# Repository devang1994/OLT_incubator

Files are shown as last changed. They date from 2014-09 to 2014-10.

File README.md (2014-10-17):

# OpenLabTools Incubator

## Introduction
The incubator project aims to make a cost-effective open-source customizable incubator from of the shelf components for use primarily in biology research

The project has been designed to be fully compatible with OpenLabTools Web interface to provide ease of control and access. Because of the web based interface the incubator can also be controlled and monitored remotely.

## Temperature Control

Peltier modules have been used as the basic heat transfer component for the incubator.
Peltier modules act as solid state heat pumps allowing us to either cool or heat the module by simply switching the current going into the module.

An off the shelf CPU heatsink with fan has been attached to both the sides of the peltier modules to effectively dissipate heat to either the surroundings or the incubation chamber.

## Electronics

A simple [H-Bridge](http://en.wikipedia.org/wiki/H_bridge) circuit was designed and made using off the shelf relays and darlington transistors. The H-Bridge is controlled by the micro-controller which allows current to pass in either direction across the peltier module allowing us to either heat or cool the system.

A DHT 22 sensor is used to detect the temperature in the box to do appropriate control.

## Microprocessor

Arduino UNO has been used as the micro-controller for this application, it can be controlled by sending the required temperature to it via the serial protocol, it also reads the temperature in the incubator and returns it via the serial protocol.

The code has been written using the Arduino IDE.

## Incubator chamber

The current  incubator chamber has been made using a 2mm acrylic sheet, this can be changed to suit particular needs of the application.

The acrylic sheet sheet has been milled using the [Shapeoko 2](http://docs.shapeoko.com/) Desktop CNC milling machine to make the required holes for fitting in the peltier modules and associated heatsinks as shown in the image below.

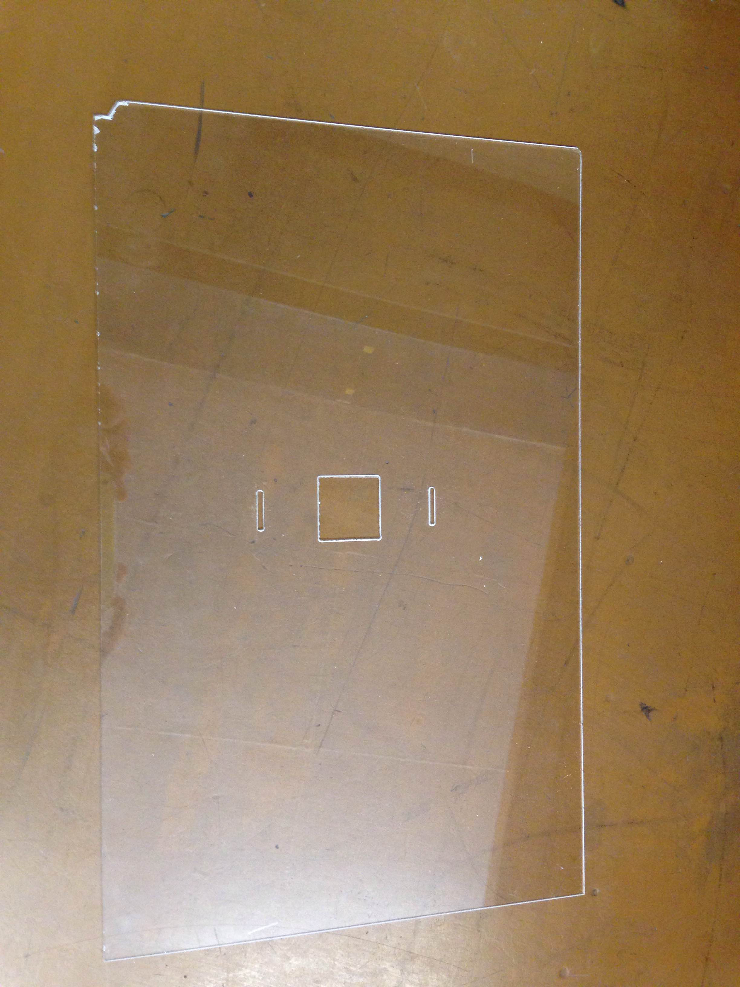
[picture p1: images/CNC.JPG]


The individual acrylic sheets are held together using angled holding brackets which were 3d printed using the MakerBot Replicator 3d printer

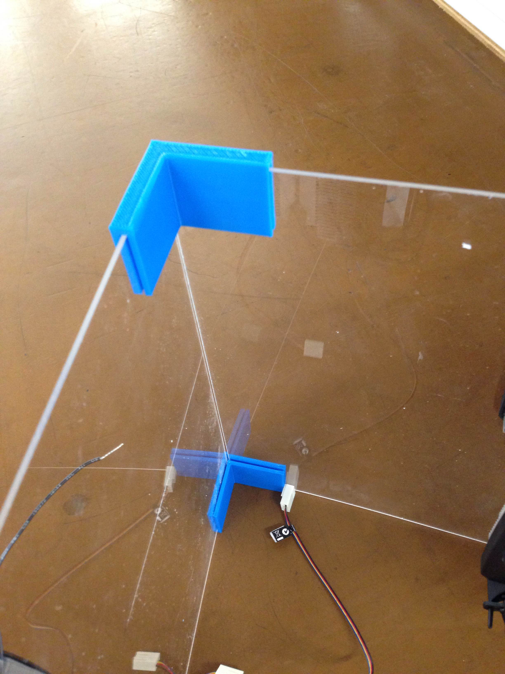
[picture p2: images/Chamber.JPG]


## Development Notes

To do:

1. Replace relays with power MOSFETs
2. Use PWM to do PID control of the temperature
3. Redesign Holding Brackets to have even smaller air gaps at joints or explore possibility of using acrylic cement or another similar product

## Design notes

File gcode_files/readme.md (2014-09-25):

Gcode instructions

The code was written using easel an online CAM package

The gcode was then sent to the shapeoko2 desktop cnc machine using universal gcode sender details about which can be found in docs.shapeoko.com

The file sideplate was used to cut the acryclic sheet to fit in the pelier modules and heatsinks into it

holding bracket was used to make a part for holding the 2 heatsinks together

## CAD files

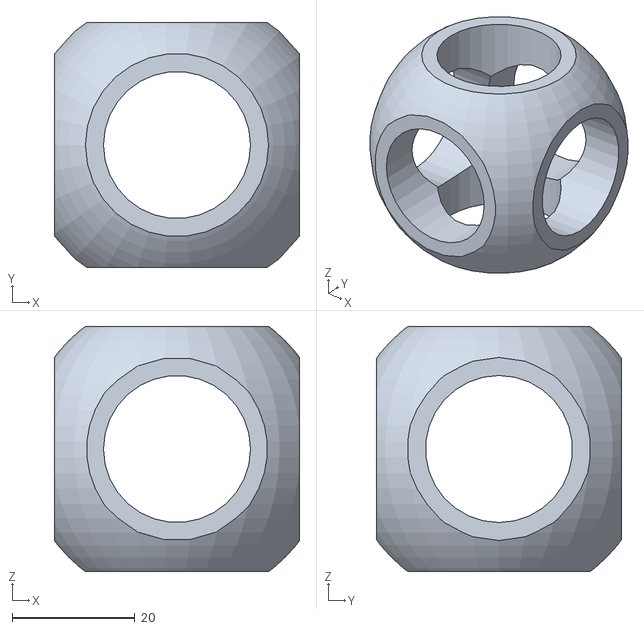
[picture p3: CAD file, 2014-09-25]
Cad_files/examples/neg_sphere.stl
40.0 x 40.0 x 40.0

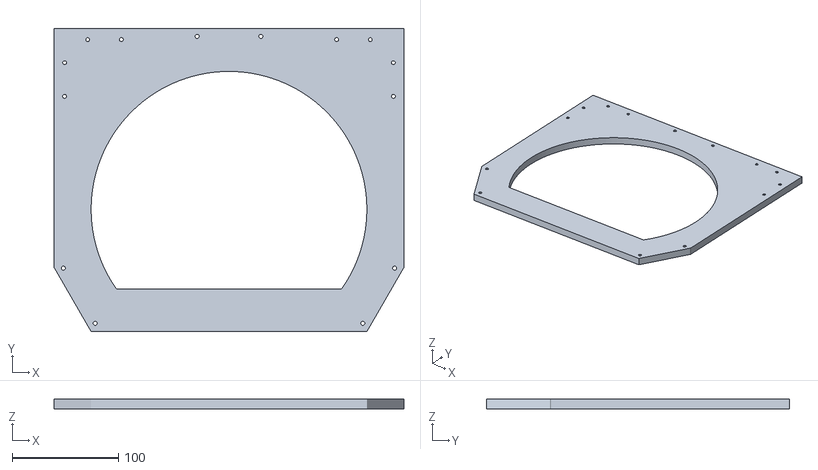
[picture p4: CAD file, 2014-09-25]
Cad_files/examples/Rostock_Bed_Design_-DXF_output/Top.stl
330.0 x 285.2 x 9.00

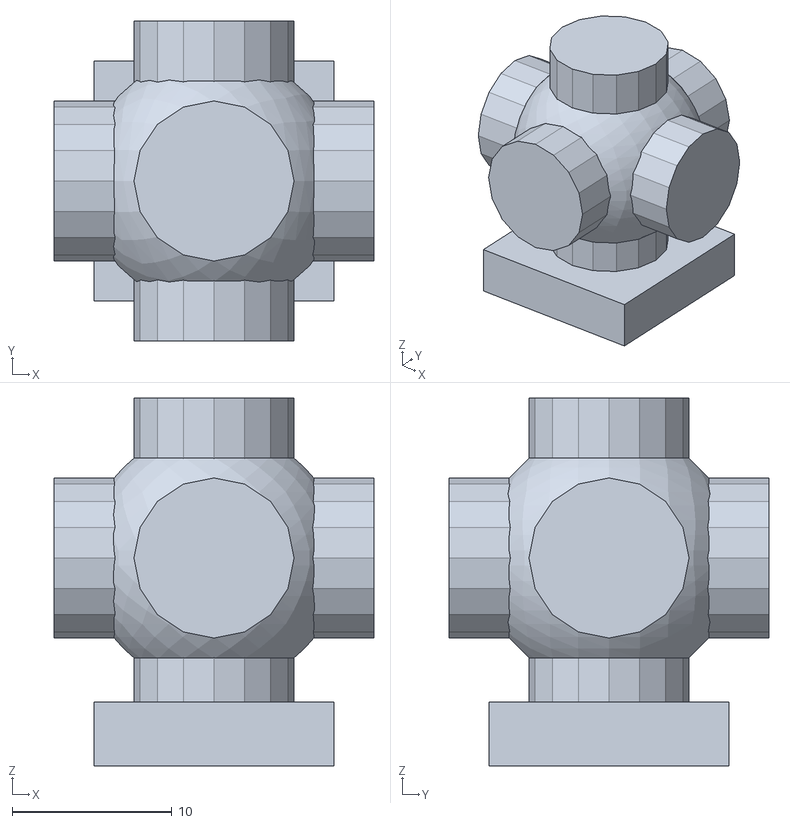
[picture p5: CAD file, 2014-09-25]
Cad_files/examples/Plus_on_Pedestal.stl
20.0 x 20.0 x 23.0

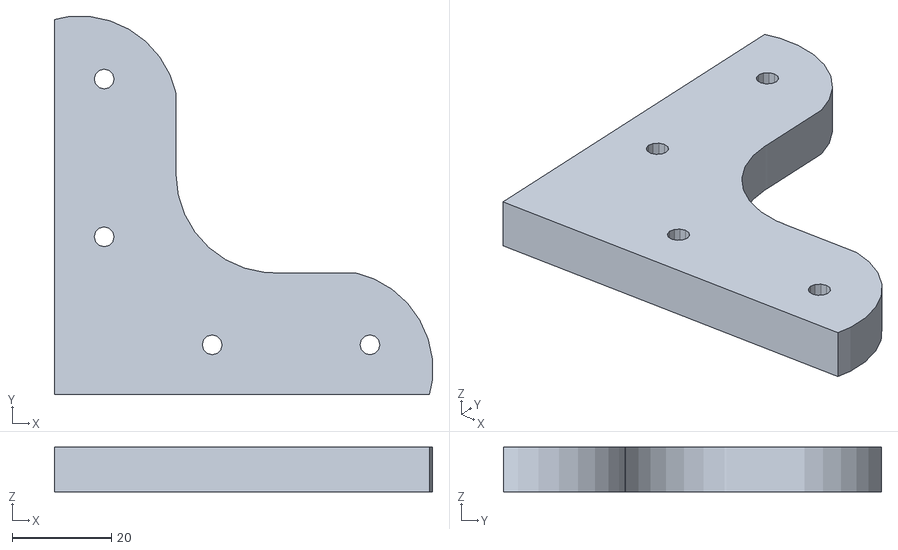
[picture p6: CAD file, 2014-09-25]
Cad_files/examples/Rostock_Bed_Design_-DXF_output/Bracket_Without_Space.stl
76.1 x 76.1 x 9.00

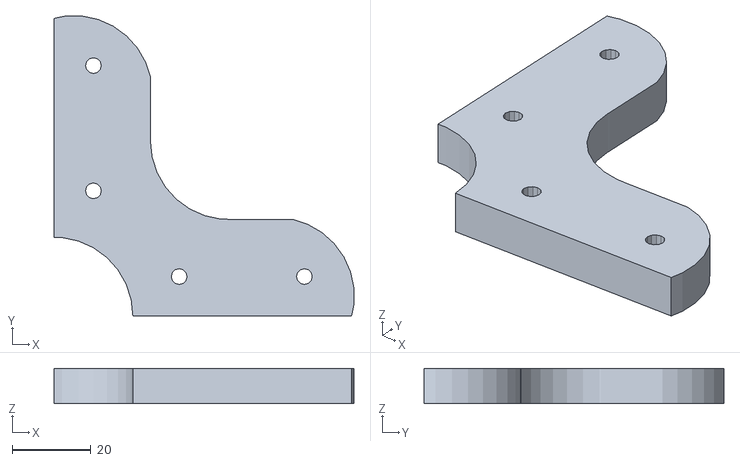
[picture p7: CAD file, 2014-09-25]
Cad_files/examples/Rostock_Bed_Design_-DXF_output/Bracket_With_Space.stl
76.1 x 76.1 x 9.00

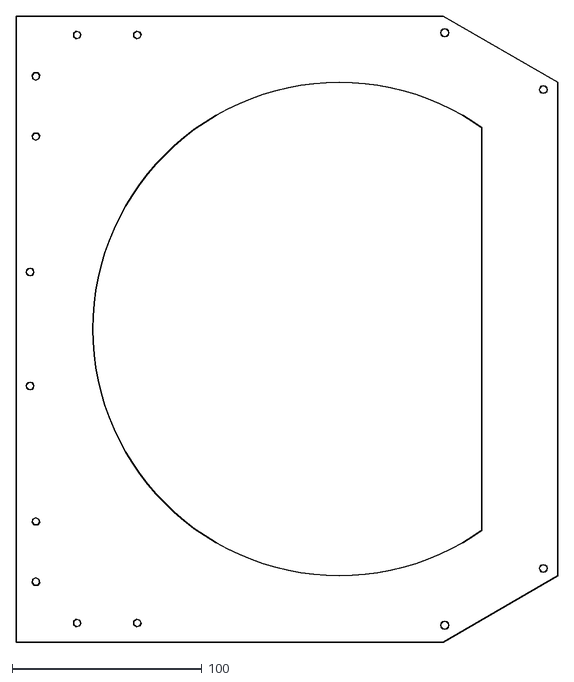
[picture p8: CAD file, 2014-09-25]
Cad_files/examples/Top.dxf
285.2 x 330.0

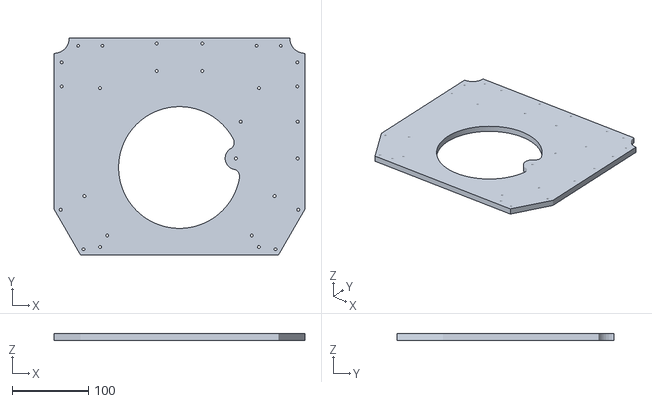
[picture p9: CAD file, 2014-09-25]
Cad_files/examples/Rostock_Bed_Design_-DXF_output/Bottom.stl
330.0 x 285.2 x 9.00

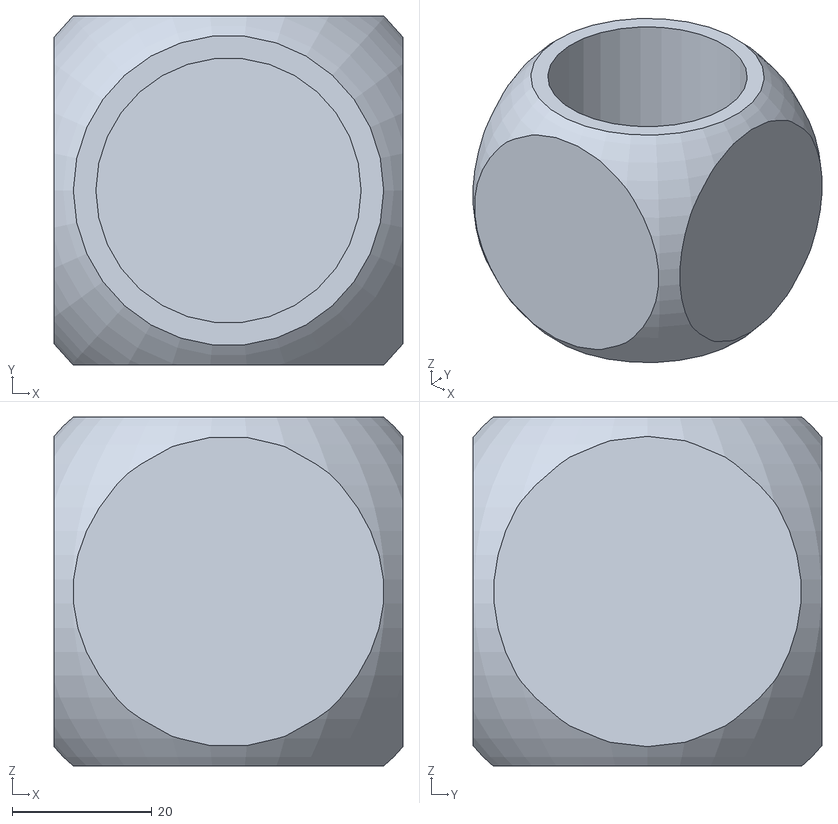
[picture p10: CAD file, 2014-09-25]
Cad_files/examples/Rounded_Box_Stuff_Holder.stl
50.0 x 50.0 x 50.0

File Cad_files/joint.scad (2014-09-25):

// A simple angle joint to hold 2 acryclic sheets to provide the basic structure
// for the incubator



module bracket(height,sheet_width)
{
	difference()
	{
		union()
		{
			cube([40,40,height]);
		}
		union()
		{
			translate([5+sheet_width,5+sheet_width,-1]) cube([40,40,height+10]);
			//gives the basic angle bracket shape
				
			translate([sheet_width+0.5,sheet_width+0.5,3]) cube ([sheet_width+0.5,40,height]);
			translate([sheet_width+0.5,sheet_width+0.5,3]) cube ([40,sheet_width+0.5,height]);
			//removes the slots for the sheet to go into
		}
	}
}

bracket(30,2);
//by changing the sheet width parameter in the module call above this can be adapted to acrylic sheets of different thicknesses

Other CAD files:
Cad_files/examples/Lesson4.scad
Cad_files/examples/Part_2_-_Rounded_Box_Stuff_Holder.scad
Cad_files/examples/Plus_on_Pedestal.scad
Cad_files/examples/Rostock_Bed_Design_-DXF_output/Bottom.dxf
Cad_files/examples/Rostock_Bed_Design_-DXF_output/Bracket_With_Space.dxf
Cad_files/examples/Rostock_Bed_Design_-DXF_output/Bracket_Without_Space.dxf
Cad_files/examples/Rostock_Bed_Design_-DXF_output/DXF_Lazercut_Bed.scad
Cad_files/examples/Untitled.scad
Cad_files/examples/Zayn_examples/mountingBracket.scad
Cad_files/examples/tut2.scad

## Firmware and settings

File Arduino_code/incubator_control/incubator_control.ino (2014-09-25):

#include "DHT.h"
#define DHTTYPE DHT22
#define DHTPIN 2
DHT dht(DHTPIN, DHTTYPE);
#define hPin 12
#define cPin 13
#define MARGIN 0.3

//takes in a temperature and tries to maintain it in the box

//tested by Devang 0n 23/9/14  comments works but as 
//is to be expected from such a control system, it overshoots a lot
//in current design PID is hard to do as relays are not good
//at handling pwm and would blow , trying to develop a more effective contol strategy
float set_temp=25;

void setup()
{
  Serial.begin(9600);
  pinMode(hPin,OUTPUT);
  pinMode(cPin,OUTPUT);
  dht.begin();
  Serial.println("enter temperature. enter 999 to nap ");
}

void loop()
{
  float t = dht.readTemperature();
  int b1=Serial.parseInt();
  if (Serial.read() == '\n') 
  {
    Serial.print("Trying to control temperature at :");
    Serial.println(b1);
    set_temp=b1;
  }
  
  
  
  if (isnan(t)) 
  {
    Serial.println("Failed to read from DHT sensor!");
  }
  else if(set_temp==999)
  {
    Serial.println("going for a nap");
    digitalWrite(hPin, LOW);
    digitalWrite(cPin, LOW);
  }
  else if (t<set_temp)
  {
    Serial.println("Heating");
    digitalWrite(hPin, HIGH);
    digitalWrite(cPin, LOW);
  }
  else if(t>set_temp)
  {
    Serial.println("Cooling");      
    digitalWrite(hPin, LOW);
    digitalWrite(cPin, HIGH);
  }  
  
  Serial.print("Temperature: "); 
  Serial.print(t);
  Serial.println(" *C "); 
  delay(3000);

}

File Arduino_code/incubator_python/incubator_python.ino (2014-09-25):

#include "DHT.h"
#define DHTTYPE DHT22
#define DHTPIN 2
DHT dht(DHTPIN, DHTTYPE);
#define hPin 12
#define cPin 13
#define MARGIN 0.2


/*gets 1 number as inputs from serial, if number is 1 it transmits temperature, 
if number is 2 it sets the desired temperature ,
by taking another input in the same line*/


/* this code is there to interface with OLT web interface*/

// the code from Incubator_control has been adapted to make it more suitable for serial communication
// with a server such as the one used for the web interface



float t;
float set_temp=28;
void setup()
{
  Serial.begin(9600);
  pinMode(hPin,OUTPUT);
  pinMode(cPin,OUTPUT);
  dht.begin();

}

void loop()
{
  
  if (Serial.available() > 0) 
  {

    // look for the next valid integer in the incoming serial stream:
    int instruction = Serial.parseInt(); //if 1 read temperature , 
    
    if(instruction==1)
    {
      t = dht.readTemperature();
      Serial.println(t);
    }

    if(instruction==2)
    {
      set_temp=Serial.parseInt();
      Serial.println("done");
      //Serial.println(set_temp);
    }

        
    
  }


  if(t<(set_temp-MARGIN))
  {
    //Serial.println("heating");
    digitalWrite(hPin, HIGH);
    digitalWrite(cPin, LOW);
  }
  if(t>(set_temp+MARGIN))
  {
    //Serial.println("Cooling");      
    digitalWrite(hPin, LOW);
    digitalWrite(cPin, HIGH);
  }
  if((t<(set_temp+MARGIN))&&(t>(set_temp-MARGIN)))
  {
    //Serial.println("going for a nap");
    digitalWrite(hPin, LOW);
    digitalWrite(cPin, LOW);
  }
}
